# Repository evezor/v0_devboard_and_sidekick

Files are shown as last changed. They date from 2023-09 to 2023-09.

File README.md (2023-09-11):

# Devboard and Sidekick
*please note this board has been deprecated.

An edge board that is meant to be a development board that breaks out all the pins. And a second board that is meant to assist, that has a small prototyping area.  

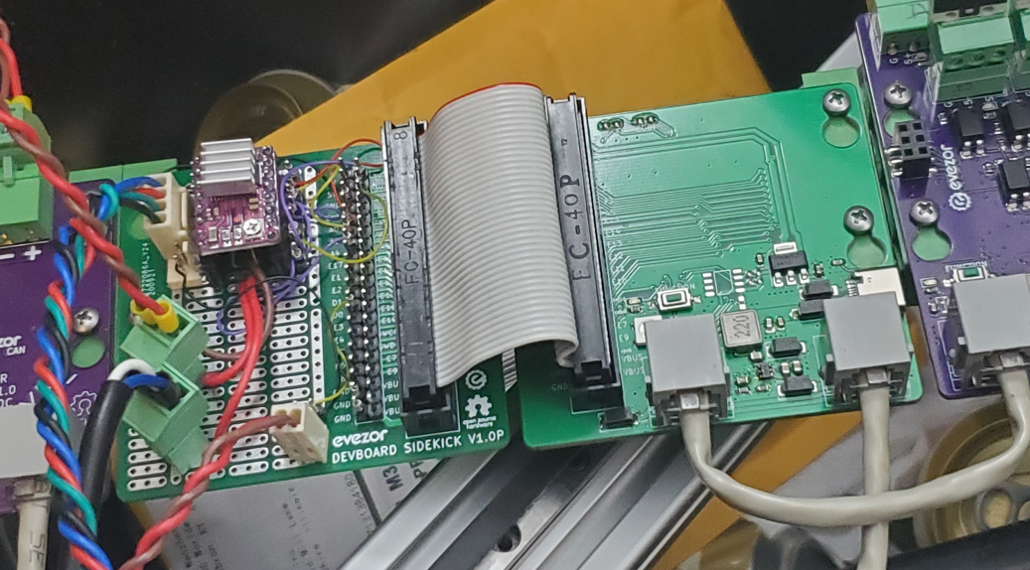
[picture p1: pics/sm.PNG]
sm


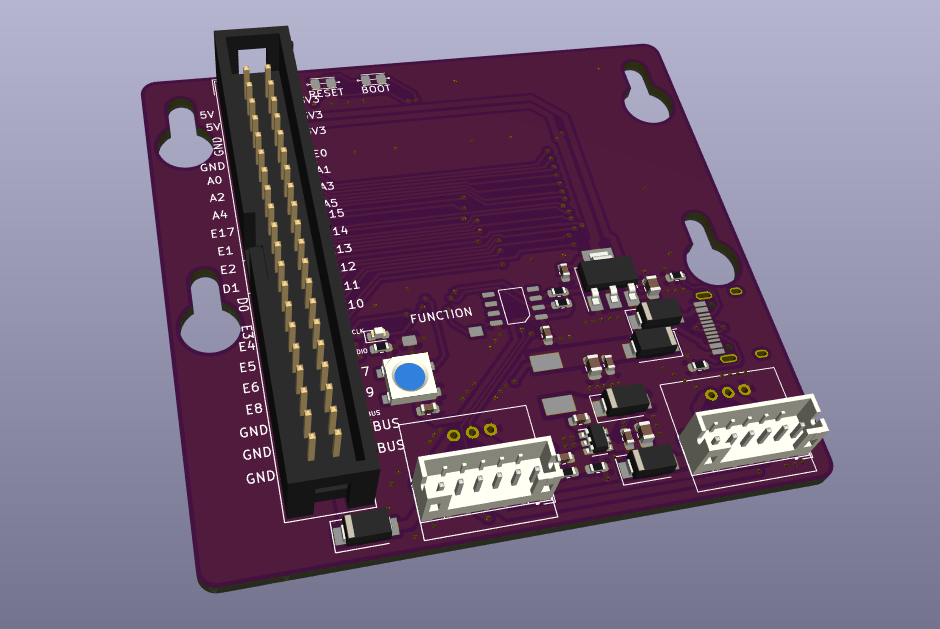
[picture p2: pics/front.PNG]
front


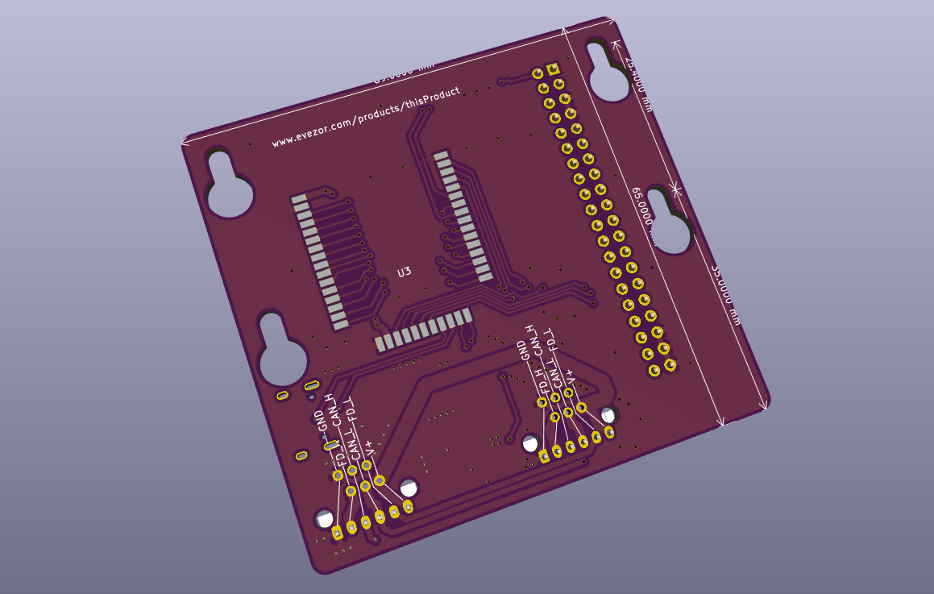
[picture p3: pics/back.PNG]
back


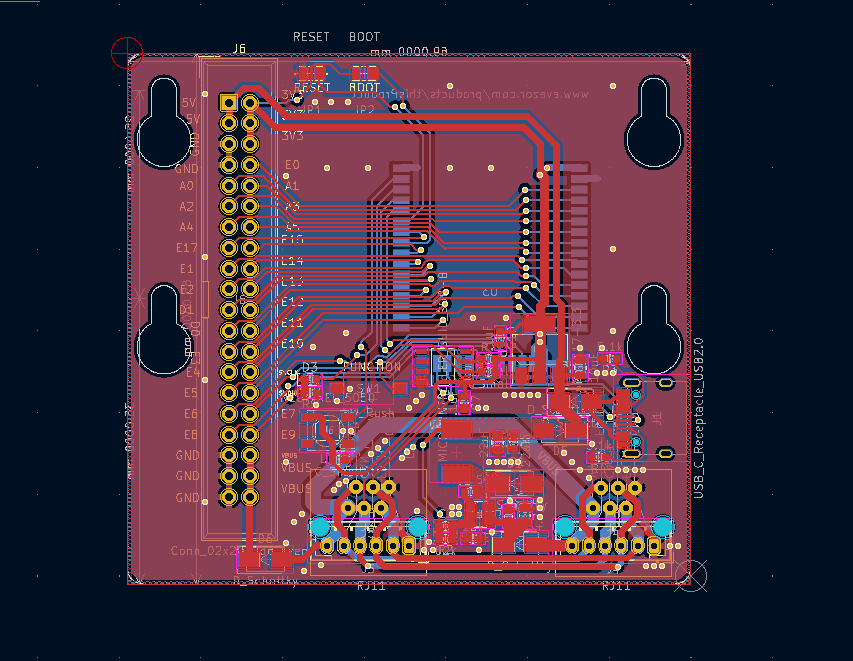
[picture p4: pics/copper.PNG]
copper


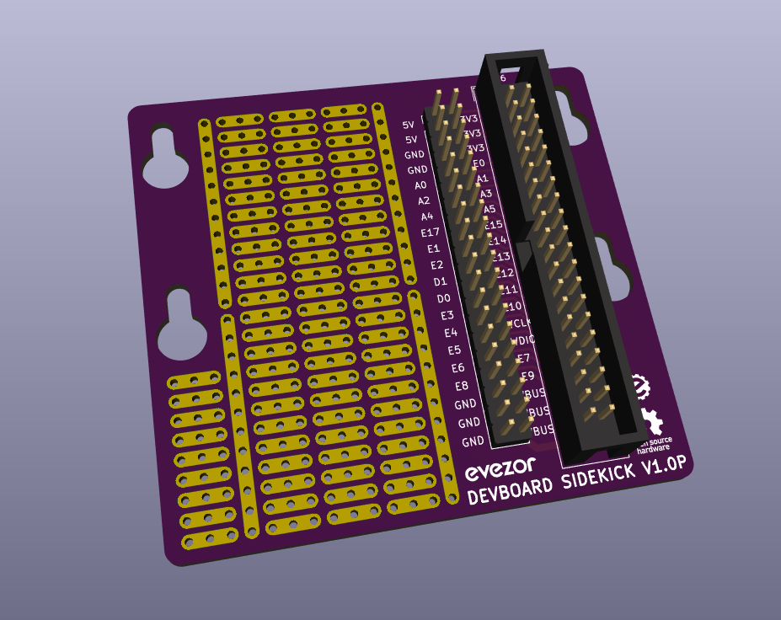
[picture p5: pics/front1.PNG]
front


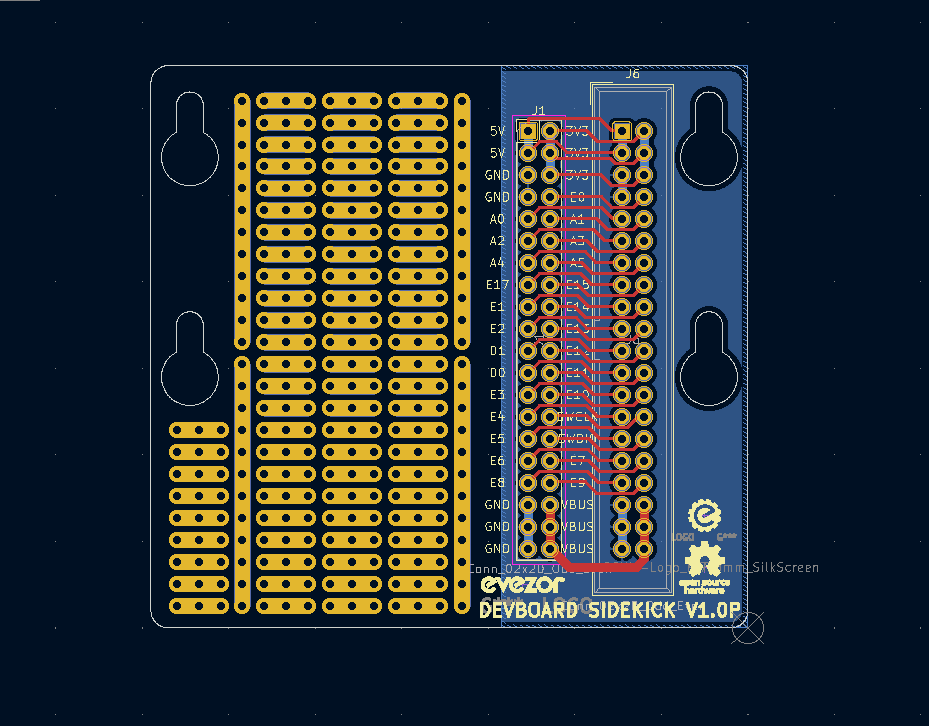
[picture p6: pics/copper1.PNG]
copper


source files can be found here: https://github.com/evezor/v0_devboard_and_sidekick

This board uses the Evezor Stamp STMF405 MCU

source: https://github.com/evezor/Evezor-Stamp-STMF405

Evezor® and all associated marks, logos, and designs are registered trademarks and protected by copyright. Unauthorized use or reproduction of these trademarks and copyrighted materials is strictly prohibited.

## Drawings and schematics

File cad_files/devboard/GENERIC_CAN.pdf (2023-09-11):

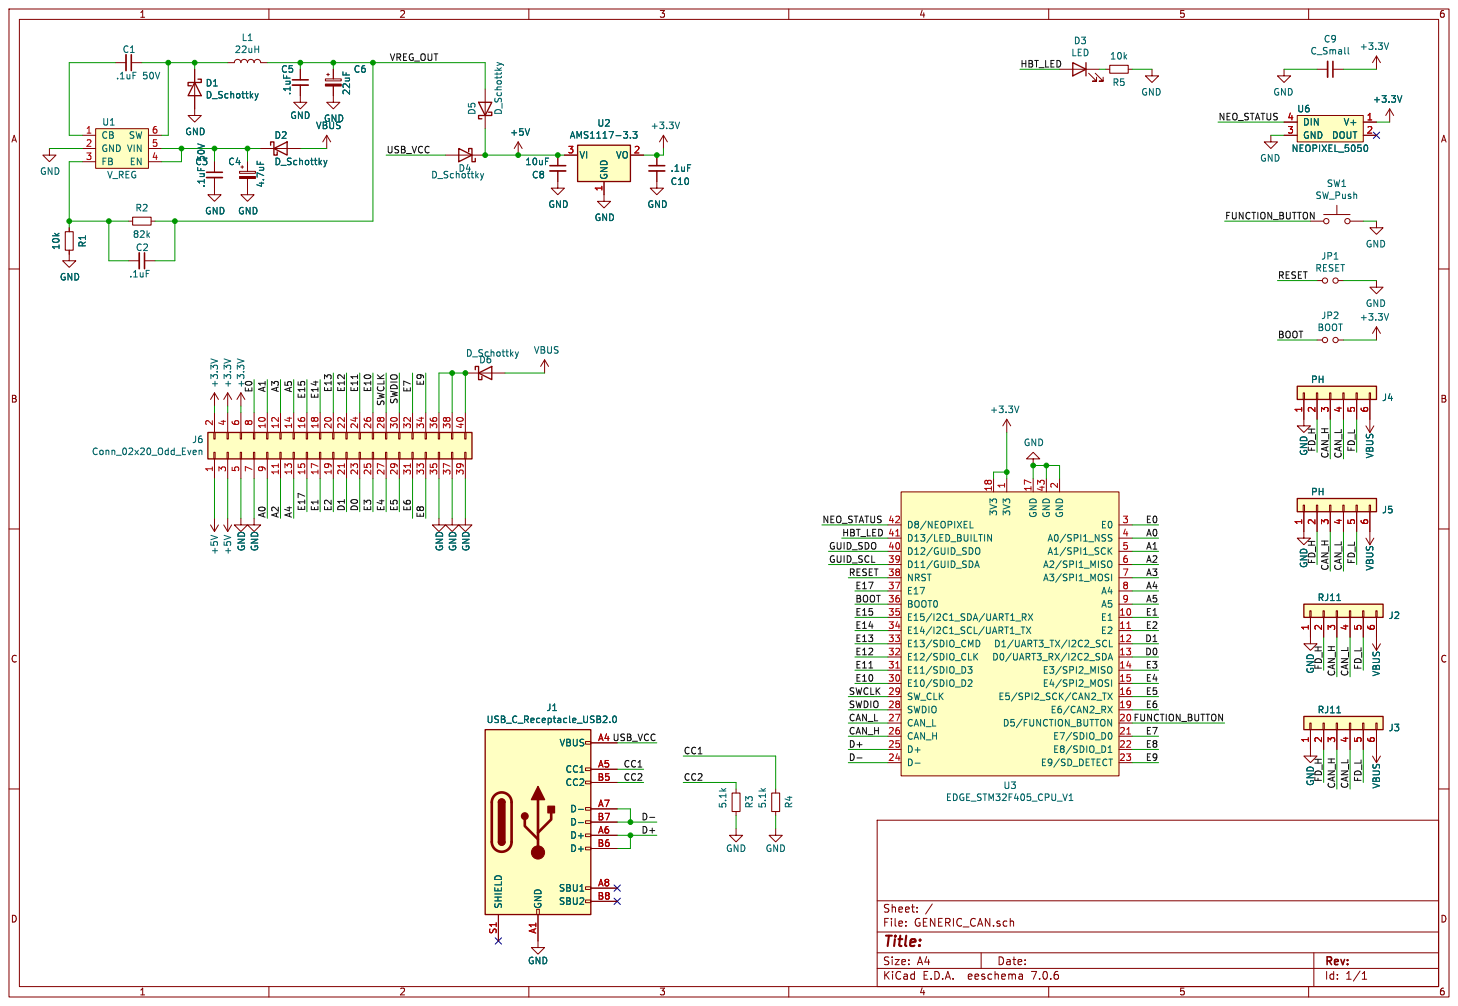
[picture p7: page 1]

6 VBUS U6 NEOPIXEL_5050 V+ 1 DOUT 2 GND 3 DIN 4 +3.3V

1 VO 2 VI 3 D2 C3 D_Schottky .1uF 50V GND GND GND GND GND

2 D5/FUNCTION_BUTTON 20 E7/SDIO_D0 21 E8/SDIO_D1 22 E9/SD_DETECT 23 D- 24 D+ 25 CAN_H 26 CAN_L 27 SWDIO 28 SW_CLK 29 E0 3 E10/SDIO_D2 30 E11/SDIO_D3 31 E12/SDIO_CLK 32 E13/SDIO_CMD 33 E14/I2C1_SCL/UART1_TX 34 E15/I2C1_SDA/UART1_RX 35 BOOT0 36 E17 37 NRST 38 D11/GUID_SDA 39 A0/SPI1_NSS 4 D12/GUID_SDO 40 D13/LED_BUILTIN 41 D8/NEOPIXEL 42 GND 43 A1/SPI1_SCK 5 A2/SPI1_MISO 6 A3/SPI1_MOSI 7 A4 8 A5 9 U3 EDGE_STM32F405_CPU_V1

Id: 1/1 Title: File: GENERIC_CAN.sch Sheet: /

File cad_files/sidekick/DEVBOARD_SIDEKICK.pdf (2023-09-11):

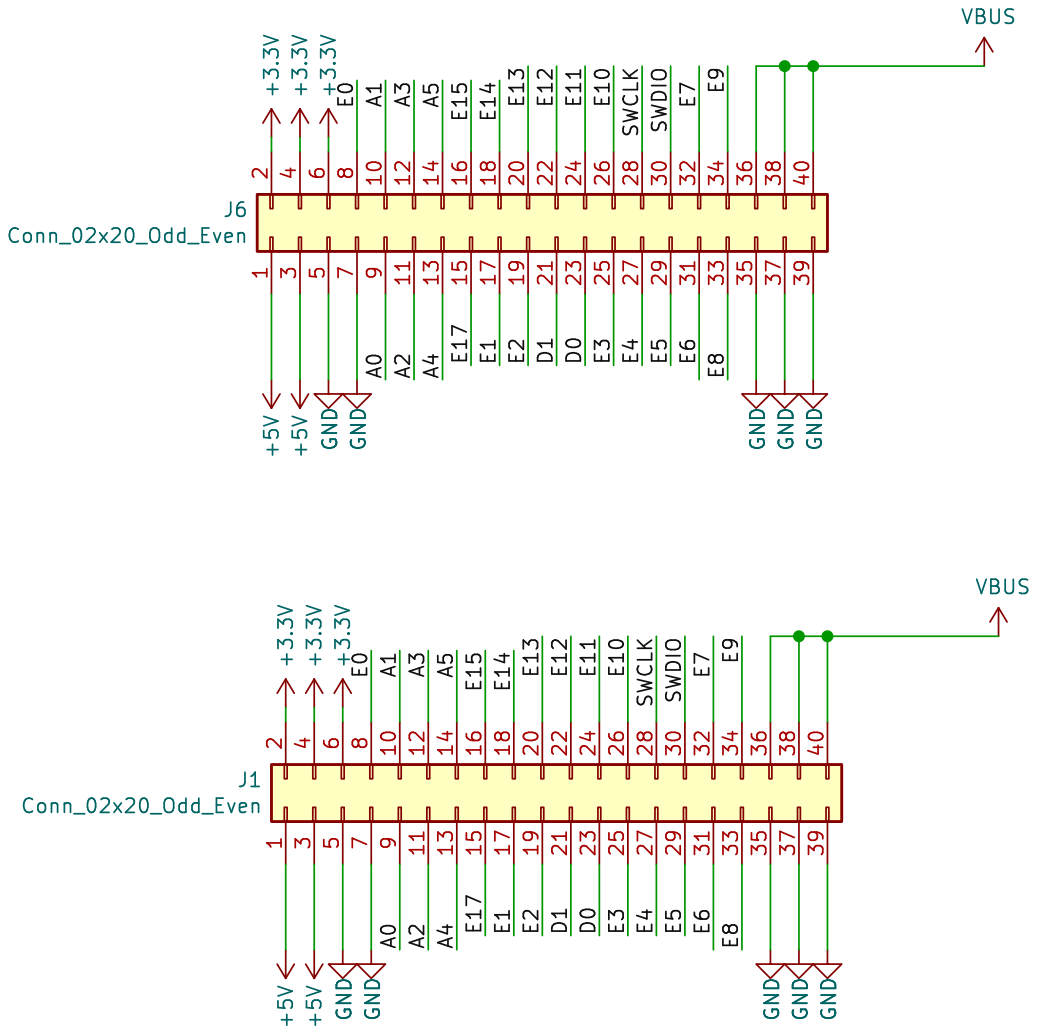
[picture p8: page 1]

VBUS GND GND GND

Id: 1/1 Title: File: DEVBOARD_SIDEKICK.sch Sheet: /

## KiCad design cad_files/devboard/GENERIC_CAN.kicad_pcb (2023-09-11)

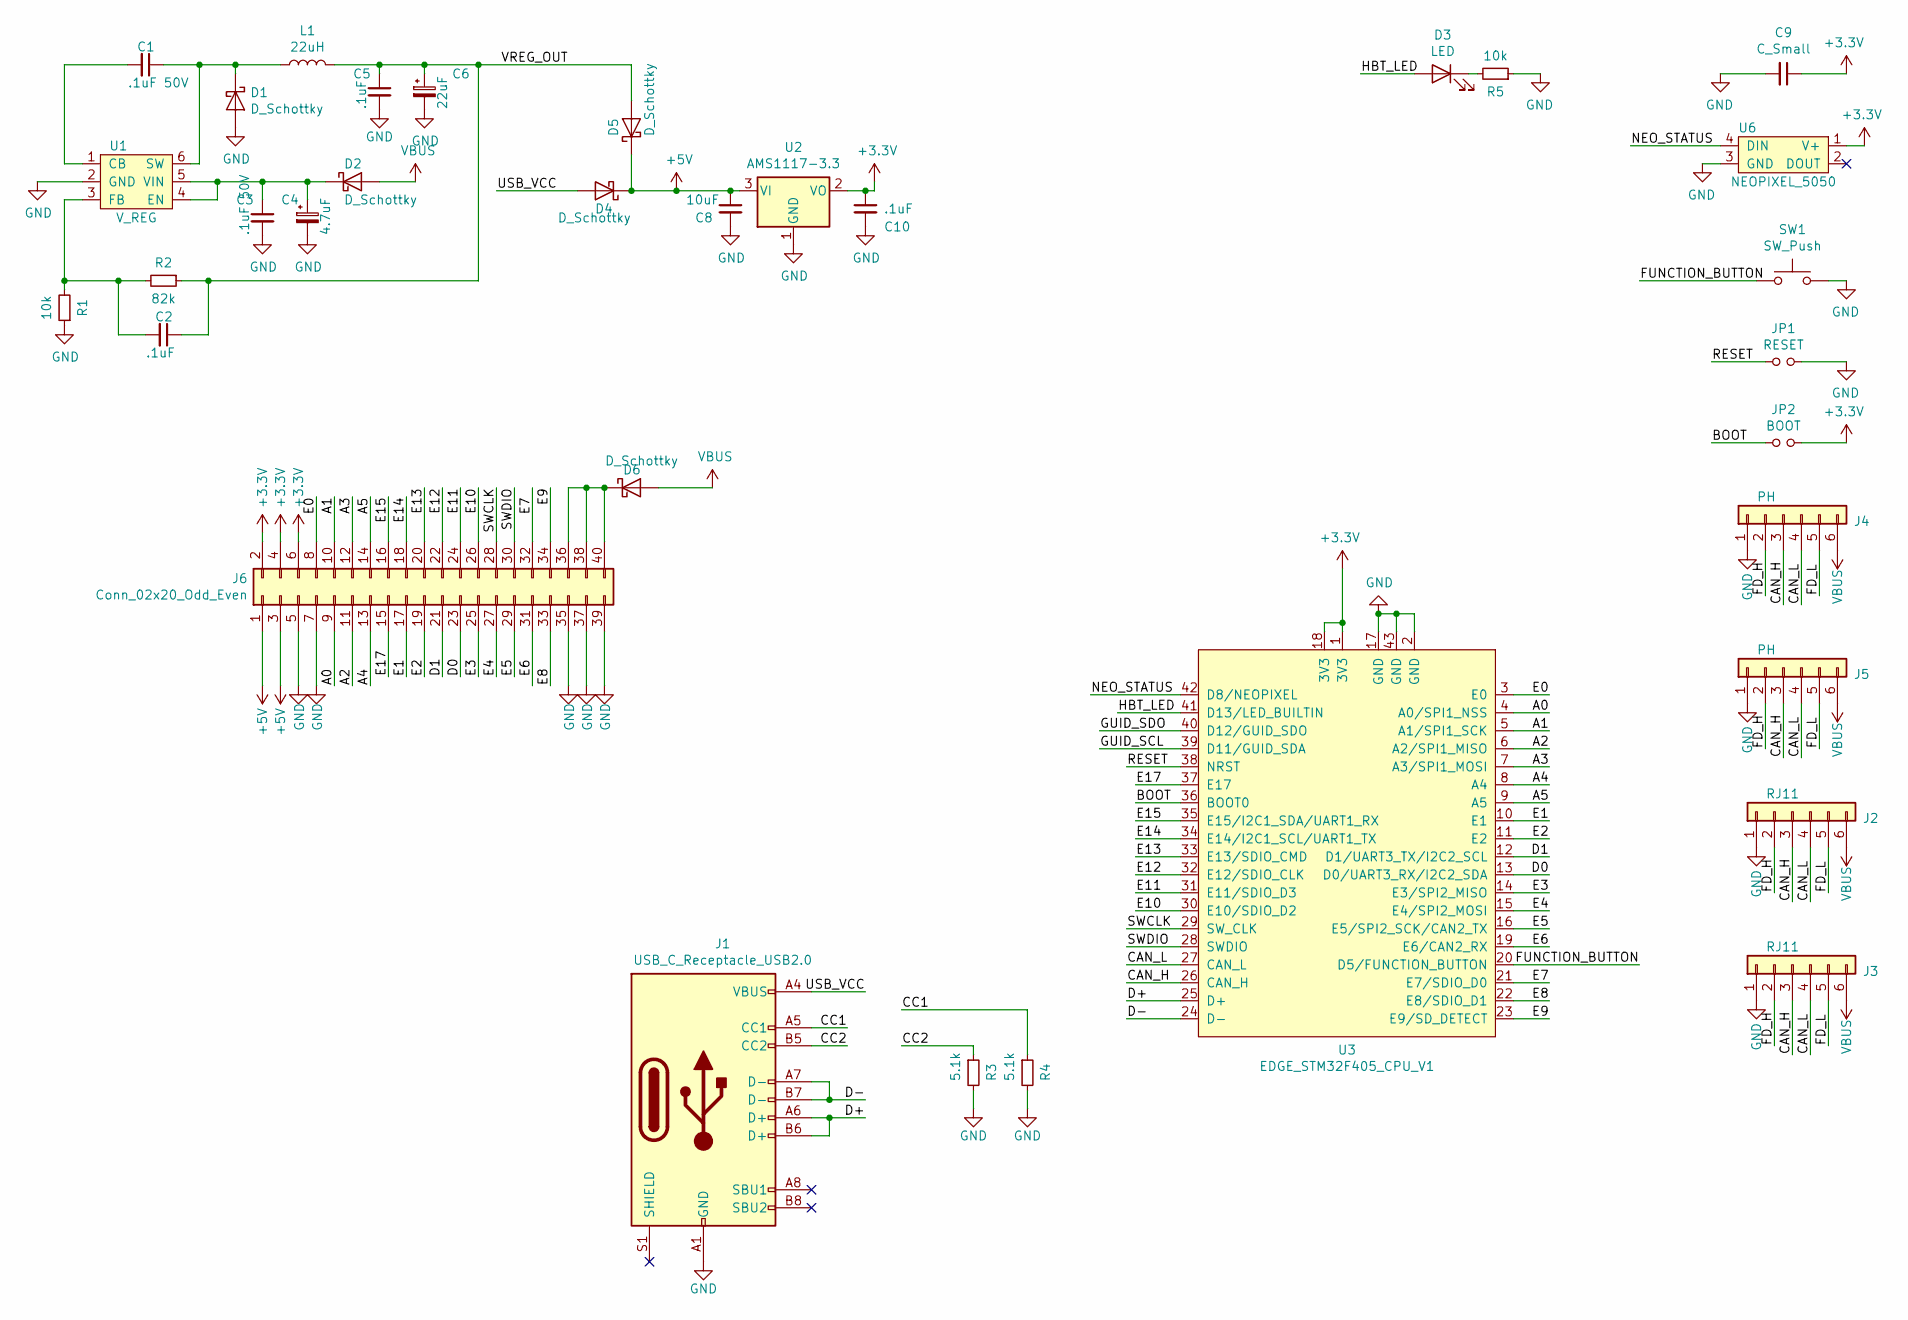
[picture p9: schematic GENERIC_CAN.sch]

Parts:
C1, C3: .1uF 50V; C_0603_1608Metric
C2, C5, C10: .1uF; C_0603_1608Metric
C4: 4.7uF; C_0805_2012Metric
C6: 22uF; C_0805_2012Metric
C8: 10uF; C_0805_2012Metric
C9: C_Small; C_0603_1608Metric
D1, D2, D4, D5, D6: D_Schottky; D_SMA
D3: LED; LED_0603_1608Metric
J1: USB_C_Receptacle_USB2.0; USB_C_Receptacle_HRO_TYPE-C-31-M-12
J2, J3: RJ11; RJ11_C189747_Horizontal
J4, J5: PH; JST_PH_B6B-PH-K_1x06_P2.00mm_Vertical
J6: Conn_02x20_Odd_Even; IDC-Header_2x20_P2.54mm_Vertical
JP1: RESET; SHORT_PAD
JP2: BOOT; SHORT_PAD
L1: 22uH; INDUCTOR_7.5X6.6_GCDA0630-220MC
R1, R5: 10k; R_0603_1608Metric
R2: 82k; R_0603_1608Metric
R3, R4: 5.1k; R_0603_1608Metric
SW1: SW_Push; SWITCH_2x3_SMD_TACTILE_GREEN
U1: V_REG; SOT-23-6
U2: AMS1117-3.3; SOT-223-3_TabPin2
U3: EDGE_STM32F405_CPU_V1; EDGE_STAMP
U6: NEOPIXEL_5050

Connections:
+3V3: C9.1, C10.1, J6.2, J6.4, J6.6, JP2.2, U2.2 (VO), U3.1 (3V3), U3.18 (3V3), U6.1 (V+); also elsewhere on the board
+5V: C8.1, D4.1 (K), D5.1 (K), J6.1, J6.3, U2.3 (VI)
/A0: J6.9, U3.4 (A0/SPI1_NSS)
/A1: J6.10, U3.5 (A1/SPI1_SCK)
/A2: J6.11, U3.6 (A2/SPI1_MISO)
/A3: J6.12, U3.7 (A3/SPI1_MOSI)
/A4: J6.13, U3.8 (A4)
/A5: J6.14, U3.9 (A5)
/BOOT: JP2.1, U3.36 (BOOT0)
/CAN_H: J2.3, J3.3, J4.3, J5.3, U3.26 (CAN_H)
/CAN_L: J2.4, J3.4, J4.4, J5.4, U3.27 (CAN_L)
/CC1: J1.A5 (CC1), R4.1
/CC2: J1.B5 (CC2), R3.1
/D0: J6.23, U3.13 (D0/UART3_RX/I2C2_SDA)
/D1: J6.21, U3.12 (D1/UART3_TX/I2C2_SCL)
/D+: J1.A6 (D+), J1.B6 (D+), U3.25 (D+)
/D-: J1.A7 (D-), J1.B7 (D-), U3.24 (D-)
/E0: J6.8, U3.3 (E0)
/E1: J6.17, U3.10 (E1)
/E2: J6.19, U3.11 (E2)
/E3: J6.25, U3.14 (E3/SPI2_MISO)
/E4: J6.27, U3.15 (E4/SPI2_MOSI)
/E5: J6.29, U3.16 (E5/SPI2_SCK/CAN2_TX)
/E6: J6.31, U3.19 (E6/CAN2_RX)
/E7: J6.32, U3.21 (E7/SDIO_D0)
/E8: J6.33, U3.22 (E8/SDIO_D1)
/E9: J6.34, U3.23 (E9/SD_DETECT)
/E10: J6.26, U3.30 (E10/SDIO_D2)
/E11: J6.24, U3.31 (E11/SDIO_D3)
/E12: J6.22, U3.32 (E12/SDIO_CLK)
/E13: J6.20, U3.33 (E13/SDIO_CMD)
/E14: J6.18, U3.34 (E14/I2C1_SCL/UART1_TX)
/E15: J6.16, U3.35 (E15/I2C1_SDA/UART1_RX)
/E17: J6.15, U3.37 (E17)
/FD_H: J2.2, J3.2, J4.2, J5.2
/FD_L: J2.5, J3.5, J4.5, J5.5
/FUNCTION_BUTTON: SW1.1, U3.20 (D5/FUNCTION_BUTTON)
/GUID_SCL: U3.39 (D11/GUID_SDA); also elsewhere on the board
/GUID_SDO: U3.40 (D12/GUID_SDO); also elsewhere on the board
/HBT_LED: D3.2 (A), U3.41 (D13/LED_BUILTIN)
/NEO_STATUS: U3.42 (D8/NEOPIXEL), U6.4 (DIN)
/RESET: JP1.1, U3.38 (NRST)
/SWCLK: J6.28, U3.29 (SW_CLK)
/SWDIO: J6.30, U3.28 (SWDIO)
/USB_VCC: D4.2 (A), J1.A4 (VBUS), J1.A9 (VBUS), J1.B4 (VBUS), J1.B9 (VBUS)
/VREG_OUT: C2.1, C5.1, C6.1, D5.2 (A), L1.2, R2.1
GND: C3.2, C4.2, C5.2, C6.2, C8.2, C9.2, C10.2, D1.2 (A), J1.A1 (GND), J1.A12 (GND), J1.B1 (GND), J1.B12 (GND), J2.1, J3.1, J4.1, J5.1, J6.5, J6.7, J6.35, J6.37, J6.39, JP1.2, R1.1, R3.2, R4.2, R5.1, SW1.2, U1.2 (GND), U2.1 (GND), U3.2 (GND), U3.17 (GND), U3.43 (GND), U6.3 (GND); also elsewhere on the board
unnamed: C1.1, D1.1 (K), L1.1, U1.6 (SW)
unnamed: C1.2, U1.1 (CB)
unnamed: C2.2, R1.2, R2.2, U1.3 (FB)
unnamed: C3.1, C4.1, D2.1 (K), U1.4 (EN), U1.5 (VIN)
unnamed: D3.1 (K), R5.2
unnamed: D6.1 (K), J6.36, J6.38, J6.40
VBUS: D2.2 (A), D6.2 (A), J2.6, J3.6, J4.6, J5.6

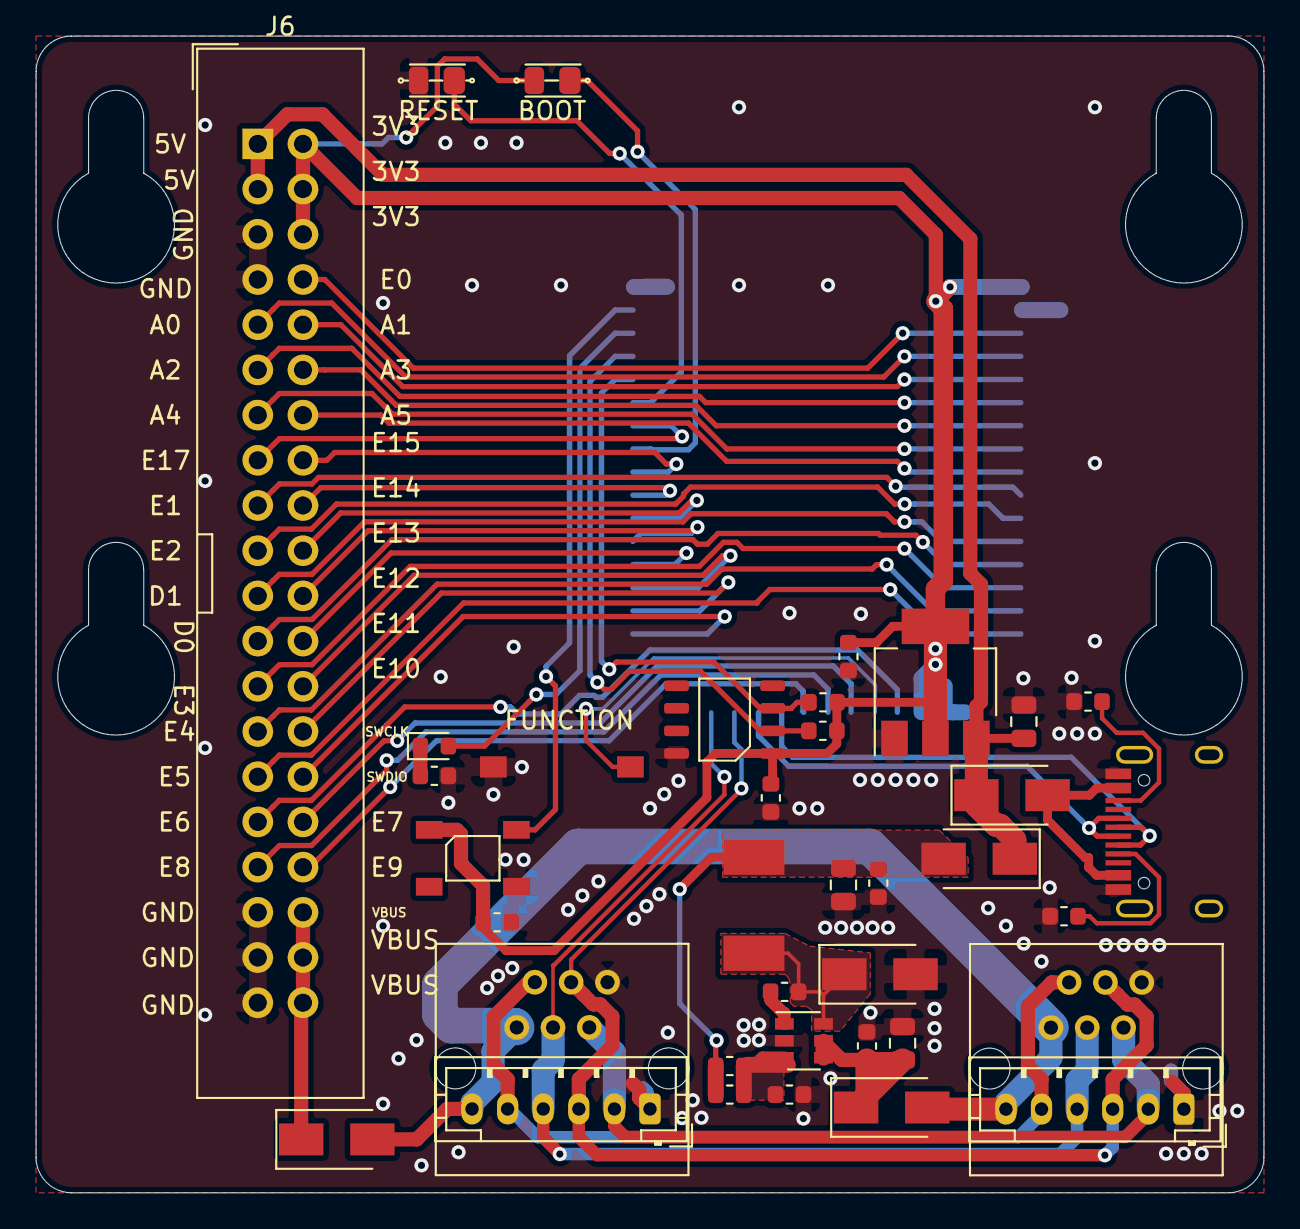
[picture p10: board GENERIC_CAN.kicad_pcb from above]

Board: 2 copper layers, 69.0 x 65.0 mm, 38 parts (1 on the bottom side), 54 nets.

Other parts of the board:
C7: .1uF; C_0603_1608Metric
R6, R7: R_Small; R_0603_1608Metric
U4: MICOCONTROLLER_GUID_SOP-8; GUID_PS150C

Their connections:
+3V3: C7.1, R6.2, R7.2, U4.1; also elsewhere on the board
/GUID_SCL: R7.1, U4.3; also elsewhere on the board
/GUID_SDO: R6.1, U4.2; also elsewhere on the board
GND: C7.2, U4.8; also elsewhere on the board
